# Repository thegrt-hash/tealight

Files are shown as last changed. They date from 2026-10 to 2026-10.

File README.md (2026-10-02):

# Tealight

A growing fleet of color-changing LED "tealights" — plus a controller that finds, pairs, and runs all of them from one web app.

- **[`device/`](device/README.md)** — firmware for each tealight itself: a Seeed XIAO ESP32-C3 + WS2812 LED in a 3D-printed shell. Standalone (button-driven) or networked (WiFi + REST API + BLE pairing).
- **[`controller/`](controller/README.md)** — firmware for one Seeed XIAO ESP32-S3 that discovers tealights over Bluetooth, provisions them onto WiFi, and serves a web app to control the whole fleet (color, effect, speed, brightness).
- **[`enclosure/`](enclosure/)** — 3D-printable body/lid for a single tealight.
- **[`BOM.md`](BOM.md)** — parts list and pricing for building a batch of tealights.
- **[`PROTOCOL.md`](PROTOCOL.md)** — the BLE/mDNS/REST contract between `device/` and `controller/`. If you're changing either firmware's networking, pairing, or REST surface, this is the file to read and update first.

## How it fits together
```
┌─────────────┐  BLE (pairing only)   ┌──────────────┐
│  Tealight   │◄─────────────────────►│  Controller  │
│ (ESP32-C3)  │                       │  (ESP32-S3)  │
│             │   WiFi (REST + mDNS)  │              │──► Web UI (browser)
│             │◄─────────────────────►│              │
└─────────────┘                       └──────────────┘
```
Each tealight is unprovisioned (and advertising over BLE) until the controller pairs it onto your WiFi. After that, the controller tracks it by a stable hardware fingerprint — not its IP — so it keeps working even after a DHCP lease changes. See [`controller/README.md`](controller/README.md) for the discovery/pairing flow and [`device/README.md`](device/README.md) for the tealight's own REST API.

Both are separate PlatformIO projects — build/flash each from its own directory:
```bash
cd device      && pio run -t upload
cd controller  && pio run -t uploadfs && pio run -t upload
```

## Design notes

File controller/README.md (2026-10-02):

# Tealight Fleet Controller

Firmware for a **Seeed XIAO ESP32-S3** that finds, pairs, and controls a
growing fleet of [tealights](../device/README.md) from one web app — no
phone app, no cloud, nothing but your LAN.

## What it does

1. **Discovers** unprovisioned tealights over Bluetooth (they advertise as
   `Tealight-XXXX` until paired).
2. **Provisions** them onto your WiFi, one at a time — connects over BLE,
   hands over your SSID/password, and waits for the tealight to confirm it
   joined.
3. **Tracks** every tealight by its hardware fingerprint, not its IP — a
   background mDNS browse re-resolves a device's current IP automatically if
   it ever changes (new DHCP lease, reboot, etc.), with an on-demand resolve
   as a fallback the moment a cached IP stops answering.
4. **Serves a web app** (open `http://<controller-ip>/` in any browser on
   the LAN) with a card per tealight: effect, color, speed, intensity,
   brightness, identify, rename, forget.

The browser only ever talks to the controller — it proxies every device
command by fingerprint, so a tealight's IP changing mid-session never breaks
the UI.

## Hardware

Just the XIAO ESP32-S3 itself — no extra parts. Flash it, power it from any
USB-C source on your network, and open its IP in a browser.

## Build & flash

Requires [PlatformIO](https://platformio.org/).

```bash
cp src/secrets.h.example src/secrets.h   # fill in your WiFi SSID/password
pio run -t uploadfs                       # upload the web UI (data/) to LittleFS
pio run -t upload                         # flash firmware over USB-C
pio device monitor                        # serial log @ 115200 — prints the controller's IP
```
`src/secrets.h` is gitignored — it's the controller's own WiFi credentials,
set at build time (there's no separate provisioning flow for the controller
itself; it's one board you flash directly).

Re-run `pio run -t uploadfs` any time you change files under `data/`.

## Adding a tealight

1. Power on a fresh tealight (or hold its button ≥3s to reset one back to
   pairing mode — see [`../device/README.md`](../device/README.md)).
2. In the web app, click **+ Add device** → **Scan for devices**.
3. Pick it from the list, enter your WiFi SSID/password and a friendly name,
   and click **Connect**.
4. Once it reports success it appears in the grid, ready to control.

## How identity survives an IP change

Every tealight has a **fingerprint** — 12 hex characters derived from its
chip's factory-burned MAC, independent of WiFi IP or BLE address. The
controller's registry (`/registry.json` on its own flash) keys everything by
fingerprint. A background task browses `_tealight._tcp` over mDNS every 15s
and refreshes each known fingerprint's IP; if a control action hits a stale
IP, the controller resolves it on the spot before giving up. You'll never
need to re-pair a tealight just because your router handed it a new address.

## REST API (consumed by the bundled web app)

| Route | Method | Body | Does |
|---|---|---|---|
| `/api/devices` | GET | — | List known devices + last-polled state |
| `/api/device/modes?fp=` | GET | — | Proxied list of that device's effects |
| `/api/device/state` | POST | `{fingerprint, ...fields}` | Proxied state patch |
| `/api/device/identify` | POST | `{fingerprint}` | Proxied locate-flash |
| `/api/device/rename` | POST | `{fingerprint, name}` | Registry only |
| `/api/device/forget` | POST | `{fingerprint}` | Registry only |
| `/api/discovery/start` | POST | — | Begin a 5s BLE scan |
| `/api/discovery/found` | GET | — | Devices found so far/after the scan |
| `/api/discovery/provision` | POST | `{address, addrType, ssid, pass, name}` | Pair one device |
| `/api/discovery/status` | GET | — | Progress of the in-flight pairing run |

## Configure

Timing (scan window, provisioning timeout, mDNS browse interval, poll
interval) and the BLE UUIDs live in [`src/config.h`](src/config.h). The BLE
UUIDs **must match** [`../device/src/config.h`](../device/src/config.h)
exactly — that's the only thing that lets the two firmwares recognize each
other.

## No hardware yet?

Everything here needs a real ESP32-S3 (NimBLE, the async web server, and
LittleFS don't have a meaningful desktop simulator) — there's no Wokwi
shortcut for the controller the way there is for a single tealight.

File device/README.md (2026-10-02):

# Mini Color-Changing LED Tealight 

A tiny battery-powered "tealight" that glows and shifts color like a candle.
Firmware for a **Seeed XIAO ESP32-C3** driving a **WS2812 / NeoPixel** RGB LED,
with a button to cycle effects.

## Effects
1. **CandleColor** — warm flame flicker with a slow color drift (default/signature look)
2. **ColorCycle** — smooth rainbow hue sweep
3. **Breathing** — brightness eases in/out over a drifting hue
4. **Solid** — static color

Color, speed, and intensity are runtime-settable (over the REST API below) —
the button only cycles which effect is active and how bright it is:

- **Short press** → next effect
- **Long press (≥0.6s)** → cycle brightness (40 / 90 / 160)
- **Hold through power-on (≥3s)** → wipe stored WiFi credentials and
  re-enter BLE pairing mode

All of this works completely standalone, with no controller present.

## Parts list

### Required
| # | Part | Notes |
|---|---|---|
| 1 | **Seeed Studio XIAO ESP32-C3** | The MCU. Any ESP32-C3 dev board works; pin labels may differ. |
| 1 | **WS2812 / WS2812B NeoPixel** | Single RGB LED — bare 5mm/PCB module, or a small ring/strip. |
| 1 | **Momentary push button** | Tactile switch, normally-open, 2-leg. |
| — | **USB-C cable** | For flashing + dev power (data-capable, not charge-only). |
| — | **Hookup wire** | Breadboard jumpers, or thin silicone wire for a soldered build. |

### Recommended (clean build / multiple LEDs)
| # | Part | Notes |
|---|---|---|
| 1 | **~330–470 Ω resistor** | In series on the LED DIN line — protects the first pixel. |
| 1 | **~1000 µF electrolytic cap (≥6.3V)** | Across LED VCC/GND — absorbs inrush, steadies power. |
| 1 | **Breadboard** | For prototyping before soldering. |

### For a battery-powered tealight (optional, finishing it off)
| # | Part | Notes |
|---|---|---|
| 1 | **3.7V LiPo cell** | e.g. 302030 / 402030 (~150–250 mAh fits a tealight shell). XIAO ESP32-C3 has an onboard LiPo charger + `BAT+`/`BAT-` pads. |
| 1 | **Slide/slider switch** | Optional hard power cutoff in the battery line. |
| — | **Diffuser** | Frosted/ping-pong ball, wax shell, or printed cap to spread the glow. |

> **Power notes:** one WS2812 at full white draws ~60 mA; code caps brightness
> so it's lower in practice. A single pixel runs fine off the XIAO's 3V3 pin.
> Only step up to a dedicated 5V rail (and the cap + resistor above) once you
> add a ring/strip of several LEDs.

## Wiring

```
  XIAO ESP32-C3                 WS2812 / NeoPixel
  ┌──────────────┐
  │ D0 (GPIO2) ──┼───────────── DIN
  │ 5V / 3V3   ──┼───────────── VCC   (5V is brightest; 3V3 works for 1 pixel)
  │ GND        ──┼──────┬────── GND
  │              │      │
  │ D1 (GPIO3) ──┼───[ button ]─┘      (button other leg -> GND; uses INPUT_PULLUP)
  └──────────────┘
```

> For more than a couple of pixels, power the LED(s) from a proper 5V rail and
> add a ~300–500Ω resistor on DIN and a ~1000µF cap across VCC/GND.

## Button (what to buy & how to wire)

Any **momentary, normally-open (NO)** push button works — the firmware uses
`INPUT_PULLUP`, so one leg goes to **D1 (GPIO3)** and the other to **GND**. No
resistor needed; debounce is handled in software.

- **Prototyping:** a standard **6×6mm through-hole tactile switch** (4-leg,
  e.g. Omron B3F-1000 or any generic 6×6×5mm). Use a *diagonal* pin pair.
- **Finished enclosure:** a **panel-mount momentary push button**. The STL's
  side hole is **7 mm** (`BTN_D` in `enclosure/tealight_case.py`) — match it to
  the button's thread/bezel. A common fit is a 7–8 mm SPST-NO momentary
  (e.g. "PBS-33B" style). Buying a 12 mm one? Just bump `BTN_D` and re-render.

Short press = next effect · long press (≥0.6 s) = brightness step.

## Battery & runtime

Target cell: **3.7 V LiPo, ~500 mAh, with a built-in protection board (PCM).**
Good form factor: **503035** (5 × 30 × 35 mm) — fits the enclosure and solders
to the XIAO's `BAT+` / `BAT-` pads (onboard charger, charges over USB-C).

Runtime estimate:

| Draw source | Typical |
|---|---|
| XIAO ESP32-C3 (radio off, running effects) | ~25 mA |
| One WS2812 at capped brightness, warm colors | ~10–15 mA |
| **Average total** | **~40 mA** |

- **500 mAh ÷ ~40 mA ≈ 10–12 h** ideal → **~8–10 h real** (LiPo usable ~85%).
- Even if draw runs high (~60–70 mA), 500 mAh still clears the **6–8 h** goal.
- Want it smaller? A **~400 mAh** cell (e.g. 402535) still gives ~7–8 h.
- Recharge: default XIAO charge current ~100 mA → full in ~5–6 h (a solder pad
  bumps this higher if you want faster charging).

> Use a **protected** LiPo. Don't fully seal the cell in with no slack — leave a
> little room and secure with foam tape, not glue directly on the pouch.

> ⚠️ **Wireless changes this math.** The table above assumes the radio is off.
> This firmware keeps **WiFi connected** (BLE provisioning + REST API + mDNS),
> which pushes average draw to roughly **80–120 mA**, cutting a 500 mAh cell to
> **~4–6 h** — possibly under the 6–8 h goal. To hit 6–8 h *with* WiFi, either
> go bigger (**~1000 mAh**, e.g. 603048) or add WiFi modem/light-sleep between
> API calls. Pure-local (radio off) still gets 8–10 h on 500 mAh.

## Cost to build (15 units)

Full priced bill of materials with vendor links: **[`../BOM.md`](../BOM.md)**.

Headline (approx, late 2026):

| Tier | 15 units | Per unit |
|---|---|---|
| **Retail** (US distributors, easy assembly) | **≈ $256** | **~$17** |
| **Budget** (bulk / overseas, more soldering) | **≈ $165–178** | **~$11–12** |

Cost drivers are the **XIAO (~$90/15)** and **LiPo (~$105/15)** — ~75% of total;
bulk-sourcing those is where the savings are. The resistor + cap are optional for
the single-pixel 3V3 build, and the diffuser prints from the same filament.

## Networking & the fleet controller

Each tealight is **API-only** — it has no web UI of its own. Out of the box
it advertises over BLE as `Tealight-XXXX`, ready to be found and paired by
the [`../controller`](../controller/README.md) web app, which assigns it a
friendly name and WiFi credentials. From then on the tealight:

- joins that WiFi network on every boot (credentials stored in flash),
- answers a small REST API on port 80:
  - `GET /api/state` / `POST /api/state` — mode, hue, sat, speed, intensity, brightness
  - `GET /api/modes` — available effects, so a client never has to hardcode the list
  - `GET /api/info` — fingerprint, name, firmware version, uptime, IP
  - `POST /api/identify` — brief white flash, for finding the physical unit
- advertises itself over mDNS as `_tealight._tcp` with its fingerprint in a
  TXT record, so the controller can re-find it if its IP ever changes.

The **fingerprint** (12 hex chars, derived from the chip's efuse MAC) is the
tealight's permanent identity — independent of WiFi IP or BLE address. If a
tealight ever needs to move to a different network, hold its button through
power-on for ≥3s to wipe its stored credentials and it'll re-advertise over
BLE for pairing again.

## Build & flash

Requires [PlatformIO](https://platformio.org/) (`pip install platformio` or the VS Code extension).

```bash
pio run                 # compile
pio run -t upload       # flash over USB-C
pio device monitor      # serial log @ 115200
```

## Configure
Pins, LED count, brightness cap, animation timing, WiFi/BLE/identify timing,
and the BLE UUIDs all live in [`src/config.h`](src/config.h). For a
ring/strip, bump `NUM_LEDS` — effects scale automatically. If you change the
BLE UUIDs, update the matching constants in
[`../controller/src/config.h`](../controller/src/config.h) too — the two
firmwares only recognize each other by those UUIDs matching exactly.

## No hardware yet?
Drop the sketch into [Wokwi](https://wokwi.com/) (ESP32-C3 + NeoPixel) to
preview the effects before parts arrive.

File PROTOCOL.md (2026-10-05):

# Device ↔ Controller Protocol

This is the contract between [`device/`](device/README.md) (the tealight
firmware) and [`controller/`](controller/README.md) (the fleet controller).
They're separate PlatformIO projects with no shared code, so this file is
the only thing keeping them in sync — **if you change any of this on one
side, update this file and the matching side in the same change.**

As of firmware **2.x**, control runs over **ESP-NOW** (connectionless 2.4 GHz),
not WiFi/HTTP. Tealights never associate to an AP — that's the whole battery
win. WiFi/REST/mDNS are gone; BLE survives only for first-run naming.

The constants below **must stay identical** in `device/src/config.h` and
`controller/src/config.h`: `BLE_SVC_UUID`, `BLE_CHR_CREDS_UUID`,
`BLE_CHR_STATUS_UUID`, `BLE_CHR_INFO_UUID`, and **`FLEET_CHANNEL`**. The ESP-NOW
packet layout in `espnow_proto.h` is duplicated verbatim in both `src/` trees
and must match byte-for-byte.

## Identity: the fingerprint

Every tealight has a **fingerprint** — 12 lowercase hex characters derived
from `ESP.getEfuseMac()` (the chip's factory-burned MAC). It's the device's
permanent identity, independent of its ESP-NOW/STA MAC and BLE address. It is
the key the controller registry (`controller/src/registry.h`) uses. The
device's **STA MAC** (the ESP-NOW address) is a separate 6-byte value the
device reports in every message; the controller stores it to unicast back.

## 0. The shared channel (read this first)

Every node — controller and all devices — must have its radio on the same
2.4 GHz channel, `FLEET_CHANNEL`. The controller is a WiFi STA on the home
network, so its radio sits on the **home AP's channel**. Therefore:

> **Lock your router's 2.4 GHz radio to a fixed channel and set
> `FLEET_CHANNEL` to that number in both configs.**

If they disagree the controller logs a warning at boot and the fleet never
hears a command. (To go router-independent, switch the controller to a SoftAP
on a hardcoded channel — a small change in `controller/src/main.cpp`.)

## 1. BLE naming (first run only)

A tealight advertises over BLE **only** while un-named, or after its button is
held ≥3 s through power-on (wipes the stored name). Once named it stops
advertising and lives purely on ESP-NOW.

- **Advertised name:** `Tealight-XXXX` (last 4 hex chars of the fingerprint)
- **Service UUID:** `e2ebef84-3a8f-4682-89dd-5d57827d5eaa`

| Characteristic | UUID | Properties | Payload |
|---|---|---|---|
| `InfoRead` | `caa25f32-b6f0-46cc-8cf6-691efcb3994e` | read | `{"fingerprint","name","fw"}` |
| `NameWrite` | `53c2f022-9349-49ef-8b56-903bfa3637b6` | write | `{"name"}` |
| `StatusNotify` | `0886dd9c-de2e-4b35-8f33-01446fb6fe39` | read, notify | `{"status","fingerprint","name"}` |

`status` is `"unnamed"` or `"named"`. (The `NameWrite` UUID is the old
`CredsWrite` UUID reused for wire-compat; it no longer carries WiFi creds.)

**Naming sequence** (controller is the BLE central):
1. Central scans, filters by the service UUID, finds the device.
2. Central connects, reads `InfoRead` for the fingerprint.
3. Central writes `{"name"}` to `NameWrite`; the device persists it, stops
   advertising, and announces itself on ESP-NOW.
4. Central records `fingerprint → name` in its registry. The MAC is filled in
   later, from the device's first ESP-NOW announce.

## 2. ESP-NOW control (everything after naming)

One fixed-size packet (`TlMsg` in `espnow_proto.h`, ~44 bytes) carries every
message. `magic = 0x7A`, `version = 1`. Commands flow controller → device
(unicast by MAC, or broadcast to `ff:ff:ff:ff:ff:ff` for the whole fleet);
reports/announces flow device → controller.

**Message types:**

| Type | Value | Direction | Meaning |
|---|---|---|---|
| `TL_CMD_SET_STATE` | 1 | ctrl → dev | apply the fields named by `fieldMask` |
| `TL_CMD_IDENTIFY` | 2 | ctrl → dev | ~2 s locate-me flash |
| `TL_CMD_QUERY` | 3 | ctrl → dev | reply with a `TL_MSG_REPORT` |
| `TL_MSG_REPORT` | 10 | dev → ctrl | full current state + identity |
| `TL_MSG_ANNOUNCE` | 11 | dev → ctrl | presence (cold boot / wake / rename) |

`fieldMask` bits (`TL_F_*`) select which of `mode/hue/sat/speed/intensity/
brightness` are meaningful — a `SET_STATE` is a **partial patch**, exactly like
the old REST `POST /api/state`. `mode` is an index into the effect list;
colour/speed fields are `0-255`. Set the `TL_FLAG_WANT_REPORT` flag to ask the
device to echo its resulting state.

Devices **announce on every wake**, so the controller's registry `lastSeenMs`
and last-known state cache refresh roughly every `IDLE_WAKE_INTERVAL_S`.

## 3. Two-tier sleep (device-side power policy)

Only **Solid** mode sleeps — the WS2812 latches its colour with no refresh.
Animated modes keep the MCU awake to push frames and never sleep.

- **Live window:** after any command or button press the device stays awake +
  listening for `LIVE_WINDOW_MS`, so repeated tweaks land instantly.
- **Idle:** it deep-sleeps, waking every `IDLE_WAKE_INTERVAL_S` to open a brief
  `RX_LISTEN_MS` listen window (and to announce). A command that arrives while
  it's asleep isn't seen until the next wake — up to `IDLE_WAKE_INTERVAL_S` of
  latency for an idle light. A button press always wakes immediately.

State survives the nap in RTC memory and is restored in `setup()`.

## Adding a new effect

1. `device/src/effects.h` — add one `Mode` enum entry (before `COUNT`).
2. `device/src/effects.cpp` — add one `fx*()` function, one `renderMode()`
   case, one `modeName()` string.
3. `controller/src/modes.h` — add the matching name in the same position.
   **This is the one list that must be kept in sync by hand** now that the
   device no longer serves `/api/modes` (it's asleep). Reuse
   `hue/sat/speed/intensity` for effect params so the generic sliders keep
   working without further controller changes.

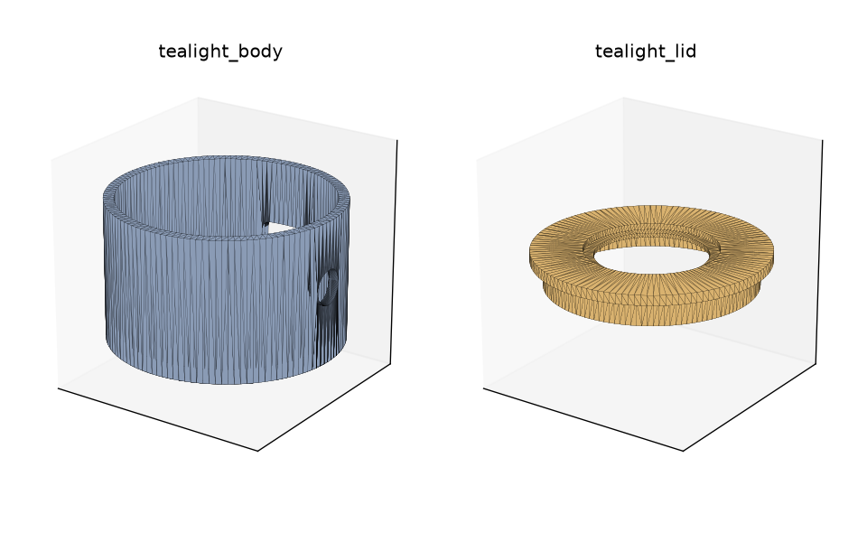
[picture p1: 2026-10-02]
enclosure/preview.png

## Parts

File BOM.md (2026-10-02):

# Bill of Materials — 15× Mini Color-Changing Tealight

Prices are approximate (late 2026) and fluctuate with vendor/region/stock.
Two tiers: **Retail** (US distributors, in hand fast, easy to assemble) and
**Budget** (bulk/overseas, cheaper, longer shipping + more soldering).

## Per-unit quantities
Each tealight needs: 1× XIAO ESP32-C3, 1× WS2812 LED, 1× 500 mAh LiPo,
1× momentary button, a few wires, printed body + lid. Resistor/cap optional.

## Retail tier (convenient)

| Part | Qty for 15 | Buy as | ~Unit | ~15-unit | Link |
|---|---|---|---|---|---|
| XIAO ESP32-C3 | 15 | singles | $5–6 | **$90** | [Seeed/PiHut](https://thepihut.com/products/seeed-xiao-esp32c3), [TME](https://www.tme.com/in/en/katalog/p,seeed-studio_1325/) |
| WS2812B LED (breakout) | 15 | singles | $1.50 | **$23** | [SparkFun](https://www.sparkfun.com/sparkfun-rgb-led-breakout-ws2812b.html) |
| LiPo 500 mAh protected (503035) | 15 | singles | $7 | **$105** | [Pi Hut](https://thepihut.com/collections/maker-store/products/500mah-3-7v-lipo-battery), [Jameco LJ503035](https://www.jameco.com/z/LJ503035-Jameco-ReliaPro-Lithium-Ion-Polymer-Battery-3-7V-500mAh-Rechargeable_2275319.html) |
| Momentary button 6×6 mm | 1×100-pack | pack | $8/pack | **$8** | [Amazon TWTADE](https://www.amazon.com/s?k=twtade+tactile+push+button) |
| Hookup wire (22 AWG set) | 1 set | set | $12 | **$12** | Amazon "22AWG hookup wire kit" |
| PLA filament (body+lid ≈30 g ea) | ~500 g | 1 kg spool | $18/kg | **$18** | Amazon / Microcenter PLA 1 kg |
| Diffuser | 15 | printed | — | **$0** | from same filament |
| Resistor + cap *(optional)* | kit | assortment | $15 | **$15** | [Walmart cap kit](https://www.walmart.com/ip/356513092) |
| **Total (w/o optional)** | | | | **≈ $256** | **≈ $17 / unit** |
| **Total (w/ resistor+cap kit)** | | | | **≈ $271** | **≈ $18 / unit** |

## Budget tier (bulk / overseas)

| Part | Qty for 15 | Buy as | ~15-unit | Notes |
|---|---|---|---|---|
| XIAO ESP32-C3 | 15 | bulk | **~$67** | ~$4.50 ea in volume |
| WS2812B | from strip | 5 m / 300-LED strip | **~$12** | cut 15 singles, solder 3 wires each ([strip](https://shillehtek.com/products/non-waterproof-ws2812b-smd-led-strip-60-led-meter-flexible-5m-roll-5v-ip30)) |
| LiPo 500 mAh | 15 | bulk | **~$60** | ~$4 ea; ensure **protected** cells |
| Button 100-pack | 1 | pack | **~$3** | eBay bulk |
| Wire | 1 | set | **~$8** | |
| PLA | 1 kg | spool | **~$15** | budget brand |
| Resistor/cap kit *(opt)* | 1 | kit | **~$13** | |
| **Total** | | | **≈ $165–178** | **≈ $11–12 / unit** |

## Notes & gotchas
- **LiPo safety/shipping:** buy cells with a built-in protection board (PCM).
  Air shipping of lithium is restricted — domestic ground is simplest; overseas
  orders can be slow or split.
- **Resistor + cap are optional** for the single-pixel, 3V3-powered build. Add
  a ~330–470 Ω series resistor on the LED data line and a ~1000 µF cap across
  LED power only if you move to 5 V or a multi-LED ring/strip.
- **USB-C cable:** need at least one *data-capable* cable for flashing; assumed
  already on hand.
- **WS2812 choice:** breakouts ($1.50) are plug-and-play; cutting a strip is
  ~10× cheaper per LED but adds 3 solder joints per unit.
- **Filament:** one 1 kg spool covers all 15 enclosures (~450–500 g) with margin.

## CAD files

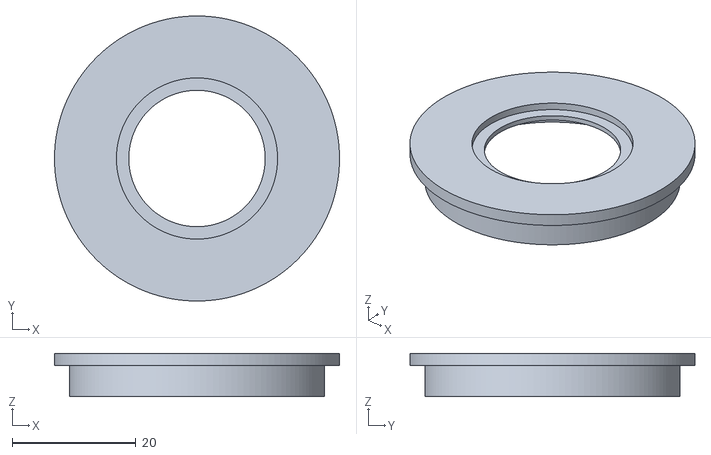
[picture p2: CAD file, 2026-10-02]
enclosure/tealight_lid.stl
46.0 x 46.0 x 7.00

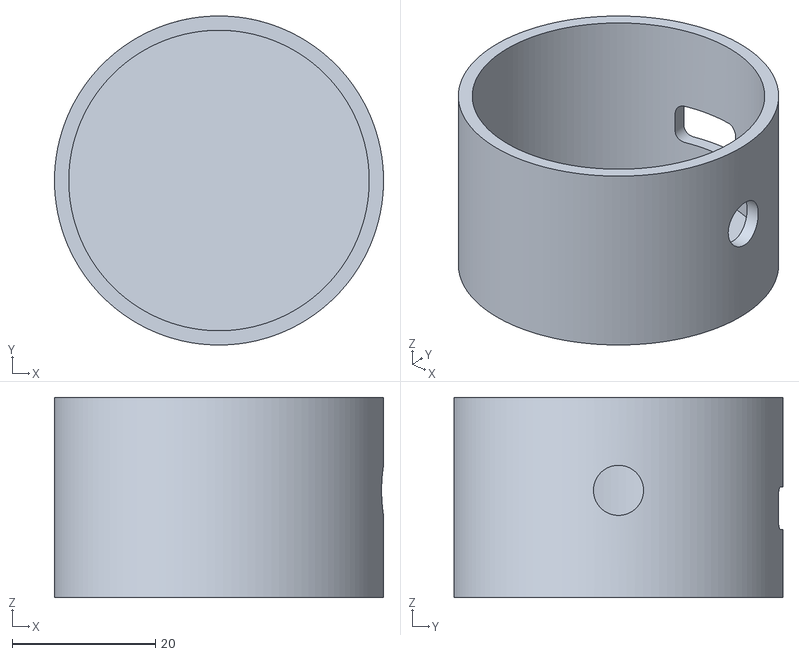
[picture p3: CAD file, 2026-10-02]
enclosure/tealight_body.stl
46.0 x 46.0 x 28.0

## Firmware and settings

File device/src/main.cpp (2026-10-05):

#include <Arduino.h>
#include <FastLED.h>
#include "config.h"
#include "effects.h"
#include "state.h"
#include "fingerprint.h"
#include "settings.h"
#include "ble_provisioning.h"
#include "espnow_device.h"
#include "power.h"

static CRGB leds[NUM_LEDS];

// ---- Non-blocking button (active-low, INPUT_PULLUP) ----
static bool     btnStable    = HIGH;
static bool     btnLastRead  = HIGH;
static uint32_t btnEdgeMs    = 0;
static uint32_t btnDownMs    = 0;
static bool     longHandled  = false;

// Short press = next mode; long press (held) = next brightness step. Both count
// as activity so the device wakes into a full live window rather than napping.
static void serviceButton(uint32_t now) {
  bool raw = digitalRead(BUTTON_PIN);

  if (raw != btnLastRead) {
    btnLastRead = raw;
    btnEdgeMs = now;
  }

  if ((now - btnEdgeMs) >= DEBOUNCE_MS && raw != btnStable) {
    btnStable = raw;
    if (btnStable == LOW) {
      btnDownMs = now;
      longHandled = false;
    } else {
      if (!longHandled) {
        Mode m = stateNextMode();
        powerNoteActivity();
        Serial.printf("[tealight] mode -> %u (%s)\n", static_cast<unsigned>(m), modeName(m));
      }
    }
  }

  if (btnStable == LOW && !longHandled && (now - btnDownMs) >= LONGPRESS_MS) {
    longHandled = true;
    uint8_t b = stateNextBrightness();
    powerNoteActivity();
    Serial.printf("[tealight] brightness -> %u\n", b);
  }
}

// Hold the button through power-on for BOOT_RESET_HOLD_MS to wipe the stored
// name and force BLE re-naming. Blocking is fine — it runs once, early.
static bool checkBootResetHold() {
  if (digitalRead(BUTTON_PIN) != LOW) return false;
  uint32_t start = millis();
  while (digitalRead(BUTTON_PIN) == LOW) {
    if (millis() - start >= BOOT_RESET_HOLD_MS) return true;
    delay(10);
  }
  return false;
}

void setup() {
  Serial.begin(MONITOR_SPEED);
  pinMode(BUTTON_PIN, INPUT_PULLUP);

  powerInit();
  bool resumed = powerResumedFromSleep();

  // Only scan for a boot-hold reset on a genuine power-on or a button wake —
  // never on a bare timer wake (keeps the 30 s listen cycle cheap).
  bool resetRequested = false;
  if (!resumed || powerWokeByButton()) resetRequested = checkBootResetHold();

  FastLED.addLeds<WS2812, LED_PIN, GRB>(leds, NUM_LEDS);
  stateInit();

  // Restore the pre-sleep look so the light comes back exactly as it was.
  DeviceState restored;
  if (resumed && powerRestoreState(restored)) stateSet(restored);

  FastLED.setBrightness(stateGet().brightness);
  FastLED.clear(true);

  settingsInit();
  if (resetRequested) {
    Serial.println("[tealight] boot-hold reset: wiping name");
    settingsClearName();
  }

  // NimBLE is only needed to name a fresh unit; skip it entirely on a timer
  // wake of an already-named device so each nap-cycle stays fast and cheap.
  bool needBle = !resumed || !settingsHasName();
  if (needBle) {
    bleInit();
    if (!settingsHasName()) bleStartAdvertising();
  }

  espnowInit();

  // Open the right-sized awake window, then tell the controller we're up.
  if (resumed && !powerWokeByButton()) powerNoteShortWindow();
  else                                 powerNoteActivity();
  espnowAnnounce();

  Serial.printf("[tealight] up — fingerprint %s, name '%s', fw %s%s\n",
                getFingerprint().c_str(), settingsName().c_str(), FW_VERSION,
                resumed ? " (resumed)" : "");
}

void loop() {
  uint32_t now = millis();

  serviceButton(now);
  espnowService(now);
  bleService(now);

  // A successful BLE naming: stop advertising, announce on ESP-NOW, and drop
  // into the normal live-window/sleep regime.
  if (bleConsumeNamedEvent()) {
    bleStopAdvertising();
    espnowAnnounce();
    powerNoteActivity();
    Serial.printf("[tealight] named '%s'\n", settingsName().c_str());
  }

  static uint32_t lastFrame = 0;
  if (now - lastFrame >= FRAME_MS) {
    lastFrame = now;
    DeviceState s = stateGet();
    if (identifyActive(now)) {
      renderIdentify(leds, now);
    } else {
      renderMode(s.mode, leds, now, s.params);
    }
    FastLED.setBrightness(s.brightness);
    FastLED.show();
  }

  // Nap if idle + Solid (see power.cpp). No-op otherwise.
  powerMaybeSleep(now, stateGet(), identifyActive(now), bleIsAdvertising());
}

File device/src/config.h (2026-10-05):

#pragma once
#include <Arduino.h>

// ---- Firmware ----
constexpr const char* FW_VERSION = "2.0.0"; // 2.x = ESP-NOW control + deep-sleep

// ---- Hardware pins (XIAO ESP32-C3 GPIO numbers) ----
// XIAO ESP32-C3 silk: D0=GPIO2, D1=GPIO3, D2=GPIO4, D3=GPIO5, D4=GPIO6, ...
constexpr uint8_t LED_PIN    = 2;   // D0  -> WS2812 DIN
constexpr uint8_t BUTTON_PIN = 3;   // D1  -> push button to GND (INPUT_PULLUP)

// ---- LED strip ----
constexpr uint16_t NUM_LEDS   = 1;   // single NeoPixel; bump for a ring/strip
constexpr uint8_t  MAX_BRIGHT = 160; // 0-255 cap (eyes + battery friendly)

// ---- Animation timing ----
constexpr uint16_t FRAME_MS = 16;   // ~60 fps render cadence

// ---- Button ----
constexpr uint16_t DEBOUNCE_MS      = 30;
constexpr uint16_t LONGPRESS_MS     = 600;   // held = brightness step
constexpr uint16_t BOOT_RESET_HOLD_MS = 3000; // held at power-on = wipe name, re-enter BLE naming

// ---- Identify (locate-me flash) ----
constexpr uint32_t IDENTIFY_FLASH_MS = 2000;

// ---- ESP-NOW fleet control ----
// The whole fleet shares ONE fixed 2.4 GHz channel. The controller is a WiFi
// STA on your home network, so its radio sits on the home AP's channel — set
// your router's 2.4 GHz radio to a FIXED channel and put that number here (and
// in controller/src/config.h). If the two disagree, devices never hear a word.
constexpr uint8_t FLEET_CHANNEL = 1;

// ---- Two-tier sleep ----
// Only Solid mode sleeps (the WS2812 latches its colour with no refresh).
// Animated modes must keep the MCU awake to push frames, so they never sleep.
//   - After any command/button ("live window") the device stays awake + RX so
//     repeated tweaks land instantly.
//   - When idle it deep-sleeps, waking every IDLE_WAKE_INTERVAL_S to open a
//     brief RX_LISTEN_MS window (and a button press always wakes immediately).
constexpr uint32_t LIVE_WINDOW_MS       = 5UL * 60UL * 1000UL; // awake+listening after a poke
constexpr uint32_t IDLE_WAKE_INTERVAL_S = 30;   // deep-sleep timer-wake cadence
constexpr uint32_t RX_LISTEN_MS         = 150;  // listen window opened on each timer wake

// ---- BLE naming (first-run only) ----
// Freshly generated, project-specific UUIDs (not reused tutorial UUIDs). A
// fresh/un-named unit advertises these so the controller can find and name it;
// once named it stops advertising and lives purely on ESP-NOW. The CREDS UUID
// is kept for wire-compat but now carries {"name": "..."} only — no WiFi creds.
constexpr const char* BLE_SVC_UUID         = "e2ebef84-3a8f-4682-89dd-5d57827d5eaa";
constexpr const char* BLE_CHR_CREDS_UUID   = "53c2f022-9349-49ef-8b56-903bfa3637b6"; // write: {name}
constexpr const char* BLE_CHR_STATUS_UUID  = "0886dd9c-de2e-4b35-8f33-01446fb6fe39"; // read+notify: {status,fingerprint,name}
constexpr const char* BLE_CHR_INFO_UUID    = "caa25f32-b6f0-46cc-8cf6-691efcb3994e"; // read: {fingerprint,name,fw}

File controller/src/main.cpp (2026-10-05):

#include <Arduino.h>
#include <WiFi.h>
#include "secrets.h"
#include "config.h"
#include "registry.h"
#include "espnow_control.h"
#include "ble_provisioner.h"
#include "web_api.h"

void setup() {
  Serial.begin(MONITOR_SPEED);
  Serial.println("[controller] booting");

  WiFi.mode(WIFI_STA);
  WiFi.begin(CONTROLLER_WIFI_SSID, CONTROLLER_WIFI_PASS);
  Serial.print("[controller] connecting to WiFi");
  while (WiFi.status() != WL_CONNECTED) {
    delay(250);
    Serial.print(".");
  }
  Serial.printf("\n[controller] WiFi up, ip=%s\n", WiFi.localIP().toString().c_str());

  registryInit();
  espnowControlInit();  // ESP-NOW command transport + report/announce intake
  bleProvisionerInit(); // BLE central: discovery + one-at-a-time naming
  webApiInit();         // REST API + web UI, async

  Serial.println("[controller] up");
}

void loop() {
  // Everything happens on background tasks and the async web server;
  // nothing needs servicing from the Arduino loop task.
  delay(1000);
}

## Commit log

2026-10-02 Initial commit: mini color-changing LED tealight
    Device firmware (XIAO ESP32-C3): FastLED effects, BLE provisioning,
    WiFi + REST API + mDNS, fingerprint identity.
    Controller firmware (XIAO ESP32-S3): BLE pairing, fingerprint-keyed
    registry, mDNS re-resolution, async web UI to control the fleet.
    Parametric CadQuery enclosure (STL body + lid) and priced BOM.
    [tealight_body.stl, tealight_lid.stl]
2026-10-02 controller: fix build — 8MB partitions, mDNS IP API, aggregate init
    - platformio.ini: board_build.partitions = default_8MB.csv (app overflowed
    default table once NimBLE + async web server + ArduinoJson linked; also
    carves the LittleFS partition for the data/ web UI).
    - mdns_browser.cpp: MDNS.address(i) -> MDNS.IP(i) (correct ESPmDNS API).
    - ble_provisioner.cpp: drop PendingProvision default member initializer so
    it stays an aggregate for brace-init (static instance is zero-initialized).
    Builds clean: firmware Flash 35.4% (1.18MB/3.3MB), LittleFS image OK.
2026-10-05 FW 2.x: ESP-NOW fleet control + two-tier deep sleep
    Replace the always-on WiFi/REST/mDNS control path (which kept the radio
    associated 24/7 and drained the battery) with connectionless ESP-NOW.
    Device (XIAO ESP32-C3):
    - espnow_device: radio parked on FLEET_CHANNEL, never associates; applies
    masked SET_STATE/IDENTIFY/QUERY commands, announces on every wake.
    - power: two-tier sleep. Solid mode deep-sleeps (WS2812 latches its colour),
    waking every IDLE_WAKE_INTERVAL_S for a brief listen + announce; any command
    or button press opens a LIVE_WINDOW_MS awake window for instant tweaks;
    button GPIO wakes immediately; state survives the nap in RTC memory.
    Animated modes stay awake to render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
    [config.h]
